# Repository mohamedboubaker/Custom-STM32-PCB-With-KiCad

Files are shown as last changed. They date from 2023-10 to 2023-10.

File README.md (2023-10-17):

# Custom STM32 PCB With KiCad
The design details are posted on EmbeddedProjects101.com: <a href="https://embeddedprojects101.com/custom-stm32-development-board/">Build a Custom STM32 PCB with KiCad</a> 

<p align="center">
  
</p>

<p align="center">
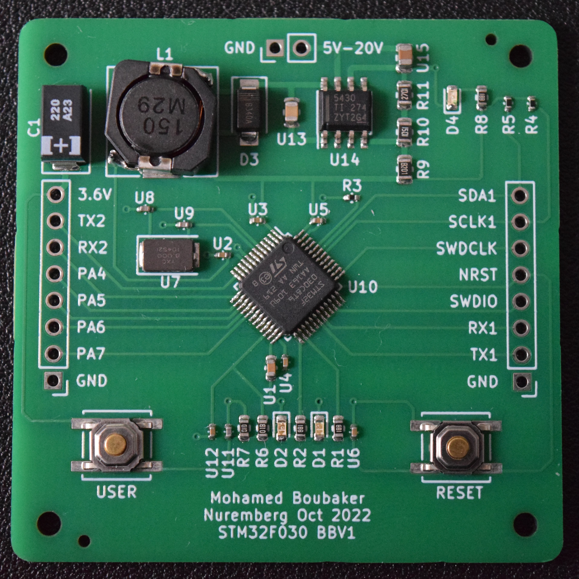
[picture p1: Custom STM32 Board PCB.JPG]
  
</p>

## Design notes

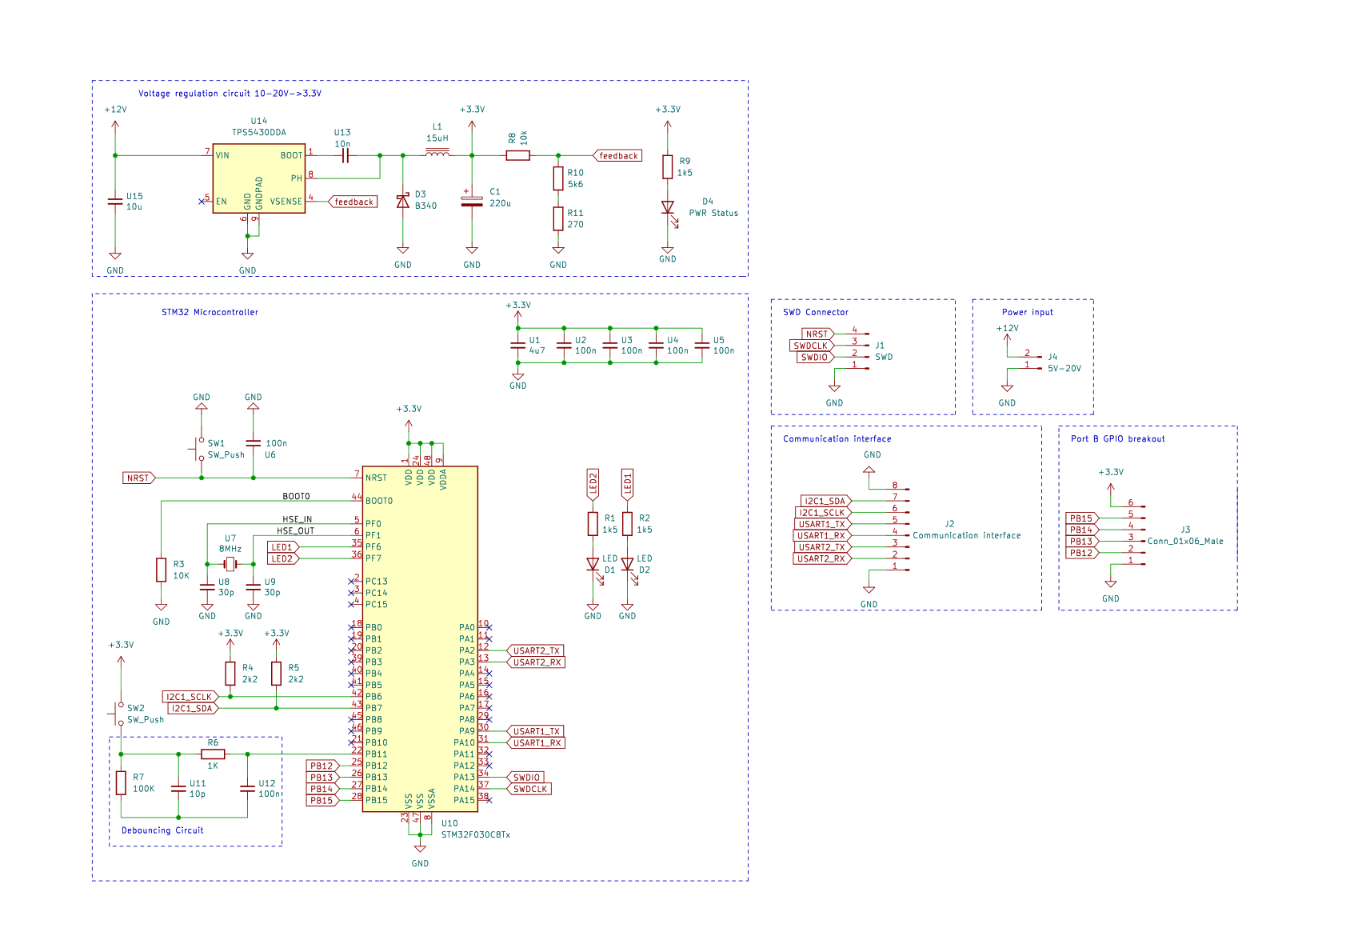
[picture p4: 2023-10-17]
circuit.png

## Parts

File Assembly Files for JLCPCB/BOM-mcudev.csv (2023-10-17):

Comment | Designator | Footprint | LCSC
220u | C1 | Capacitor_Tantalum_SMD:CP_EIA-7343-15_Kemet-W | C242173
LED1 | D1 | LED_SMD:LED_0603_1608Metric | C72043
LED2 | D2 | LED_SMD:LED_0603_1608Metric | C72041
B340 | D3 | Diode_SMD:D_SMA | C64982
PWR Status | D4 | LED_SMD:LED_0603_1608Metric | C2286
MountingHole | H1,H2,H3,H4 | MountingHole:MountingHole_2.2mm_M2
Communication pins | J1,J2 | Connector_PinHeader_2.54mm:PinHeader_1x08_P2.54mm_Vertical
5V-20V | J4 | Connector_PinHeader_2.54mm:PinHeader_1x02_P2.54mm_Vertical
15uH | L1 | Inductor_SMD:L_10.4x10.4_H4.8 | C225048
1k5 | R1,R2,R8 | Resistor_SMD:R_0603_1608Metric | C22843
1k5 | R10 | Resistor_SMD:R_0805_2012Metric | C4310
2k7 | R11 | Resistor_SMD:R_0805_2012Metric | C17530
10K | R3 | Resistor_SMD:R_0402_1005Metric | C25744
2k2 | R4,R5 | Resistor_SMD:R_0402_1005Metric | C25879
1K | R6 | Resistor_SMD:R_0603_1608Metric | C21190
100K | R7 | Resistor_SMD:R_0603_1608Metric | C25803
8k2 | R9 | Resistor_SMD:R_0805_2012Metric | C17828
SW_Push | SW1,SW2 | Button_Switch_SMD:SW_Push_1P1T_NO_CK_KSC6xxJ | C318884
4u7 | U1 | Capacitor_SMD:C_0603_1608Metric | C19666
STM32F030C8Tx | U10 | Package_QFP:LQFP-48_7x7mm_P0.5mm | C23922
10p | U11 | Capacitor_SMD:C_0402_1005Metric | C32949
10n | U13 | Capacitor_SMD:C_0805_2012Metric | C1710
TPS5430DDA | U14 | Package_SO:TI_SO-PowerPAD-8_ThermalVias | C9864
10u | U15 | Capacitor_SMD:C_0805_2012Metric | C15850
100n | U2,U3,U4,U5,U6,U12 | Capacitor_SMD:C_0402_1005Metric | C1525
8MHz | U7 | Crystal:Crystal_SMD_5032-2Pin_5.0x3.2mm | C115962
30p | U8,U9 | Capacitor_SMD:C_0402_1005Metric | C1570

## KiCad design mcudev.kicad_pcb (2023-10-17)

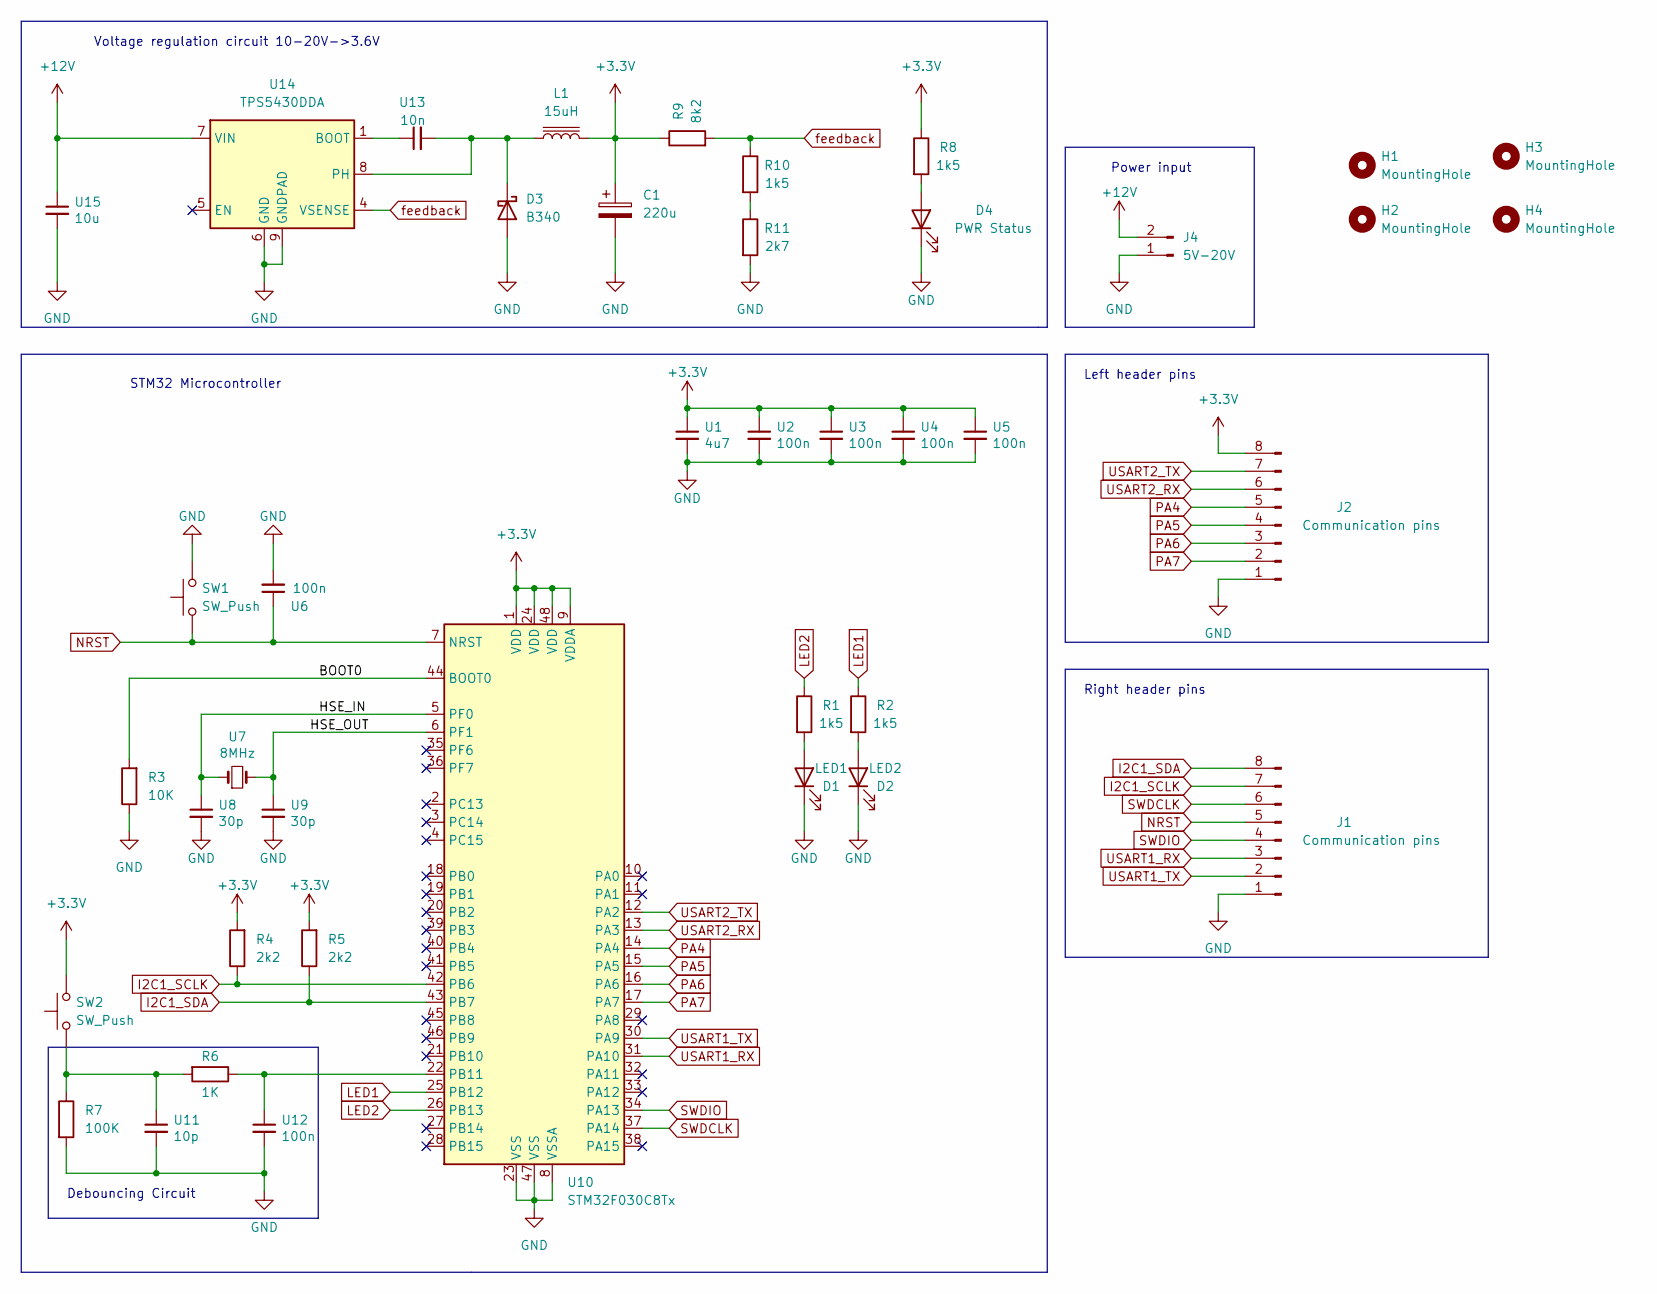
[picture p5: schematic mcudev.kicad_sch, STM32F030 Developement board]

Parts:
C1: 220u; CP_EIA-7343-15_Kemet-W; LCSC Part # C242173
D1: LED1; LED_0603_1608Metric; LCSC Part # C72043
D2: LED2; LED_0603_1608Metric; LCSC Part # C72041
D3: B340; D_SMA; LCSC Part # C64982
D4: PWR Status; LED_0603_1608Metric; LCSC Part # C2286
H1, H2, H3, H4: MountingHole; MountingHole_2.2mm_M2
J1, J2: Communication pins; PinHeader_1x08_P2.54mm_Vertical
J4: 5V-20V; PinHeader_1x02_P2.54mm_Vertical
L1: 15uH; L_10.4x10.4_H4.8; LCSC Part # C225048
R1, R2, R8: 1k5; R_0603_1608Metric; LCSC Part # C22843
R3: 10K; R_0402_1005Metric; LCSC Part # C25744
R4, R5: 2k2; R_0402_1005Metric; LCSC Part # C25879
R6: 1K; R_0603_1608Metric; LCSC Part # C21190
R7: 100K; R_0603_1608Metric; LCSC Part # C25803
R9: 8k2; R_0805_2012Metric; LCSC Part # C17828
R10: 1k5; R_0805_2012Metric; LCSC Part # C4310
R11: 2k7; R_0805_2012Metric; LCSC Part # C17530
SW1, SW2: SW_Push; SW_Push_1P1T_NO_CK_KSC6xxJ; LCSC Part # C318884
U1: 4u7; C_0603_1608Metric; LCSC Part # C19666
U2, U3, U4, U5, U6, U12: 100n; C_0402_1005Metric; LCSC Part # C1525
U7: 8MHz; Crystal_SMD_5032-2Pin_5.0x3.2mm; LCSC Part # C115962
U8, U9: 30p; C_0402_1005Metric; LCSC Part # C1570
U10: STM32F030C8Tx; LQFP-48_7x7mm_P0.5mm; LCSC Part # C23922
U11: 10p; C_0402_1005Metric; LCSC Part # C32949
U13: 10n; C_0805_2012Metric; LCSC Part # C1710
U14: TPS5430DDA; TI_SO-PowerPAD-8_ThermalVias; LCSC Part # C9864
U15: 10u; C_0805_2012Metric; LCSC Part # C15850

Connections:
+3.3V: C1.1, J2.8, L1.2, R4.2, R5.2, R8.1, R9.1, SW2.2, U1.1, U2.1, U3.1, U4.1, U5.1, U10.1 (VDD), U10.9 (VDDA), U10.24 (VDD), U10.48 (VDD)
+12V: J4.2, U14.7 (VIN), U15.1
/BOOT0: R3.2, U10.44 (BOOT0)
/HSE_IN: U7.1, U8.1, U10.5 (PF0)
/HSE_OUT: U7.2, U9.1, U10.6 (PF1)
GND: C1.2, D1.1 (K), D2.1 (K), D3.2 (A), D4.1 (K), J1.1, J2.1, J4.1, R3.1, R7.2, R11.2, SW1.2, U1.2, U2.2, U3.2, U4.2, U5.2, U6.2, U8.2, U9.2, U10.8 (VSSA), U10.23 (VSS), U10.47 (VSS), U11.2, U12.2, U14.6 (GND), U14.9 (GNDPAD), U15.2
I2C1_SCLK: J1.7, R4.1, U10.42 (PB6)
I2C1_SDA: J1.8, R5.1, U10.43 (PB7)
LED1: R2.1, U10.25 (PB12)
LED2: R1.1, U10.26 (PB13)
NRST: J1.5, SW1.1, U6.1, U10.7 (NRST)
unnamed: D1.2 (A), R1.2
unnamed: D2.2 (A), R2.2
unnamed: D3.1 (K), L1.1, U13.2, U14.8 (PH)
unnamed: D4.2 (A), R8.2
unnamed: R6.1, U10.22 (PB11), U12.1
unnamed: R6.2, R7.1, SW2.1, U11.1
unnamed: R10.2, R11.1
unnamed: U13.1, U14.1 (BOOT)
PA4: J2.5, U10.14 (PA4)
PA5: J2.4, U10.15 (PA5)
PA6: J2.3, U10.16 (PA6)
PA7: J2.2, U10.17 (PA7)
SWDCLK: J1.6, U10.37 (PA14)
SWDIO: J1.4, U10.34 (PA13)
USART1_RX: J1.3, U10.31 (PA10)
USART1_TX: J1.2, U10.30 (PA9)
USART2_RX: J2.6, U10.13 (PA3)
USART2_TX: J2.7, U10.12 (PA2)
feedback: R9.2, R10.1, U14.4 (VSENSE)

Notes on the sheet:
Power input
STM32 Microcontroller
Voltage regulation circuit 10-20V->3.6V
Right header pins
Debouncing Circuit
Left header pins

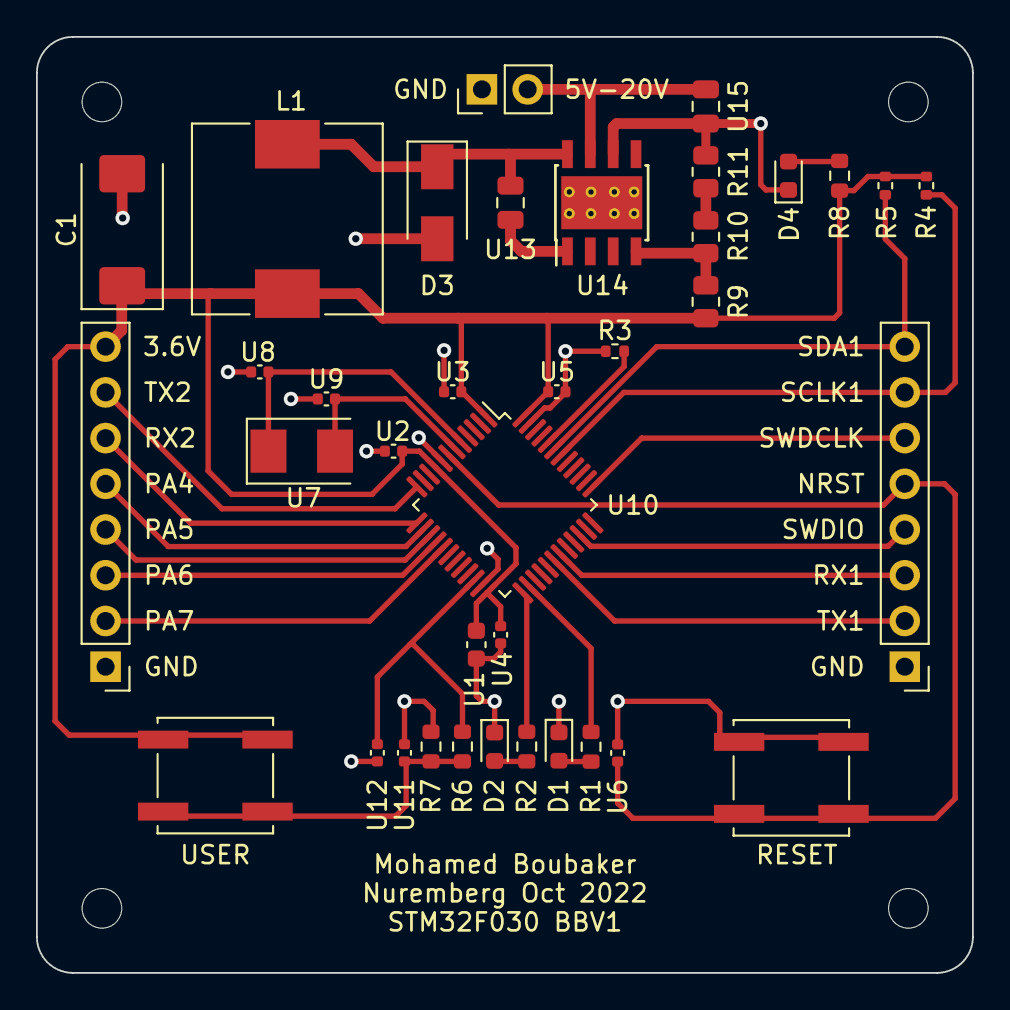
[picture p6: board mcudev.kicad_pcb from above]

Board: 2 copper layers, 52.0 x 52.0 mm, 41 parts (0 on the bottom side), 30 nets.

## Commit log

2023-10-17 added PCB picture
2023-10-17 added PCB GIF
